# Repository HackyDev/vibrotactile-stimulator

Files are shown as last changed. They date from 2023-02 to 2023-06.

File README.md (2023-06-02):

# vibrotactile-stimulator

This DIY device is for vibrotactile stimulation and consists of 8 vibration modules and a NodeMCU controller. The frequency, vibration duration, and other settings can be adjusted using a web browser through WIFI. It can be built for less than $20  (access to a 3D printer required).

This device does not have a specific designated use, so it can be used for any purpose of your choice. The initial settings are set to zero, and you will need to adjust them through a graphical interface to your own values.

Please note that this device was built by a hobbyist for personal use only and has not been tested to meet any safety standards or requirements. The code running on the controller may also contain bugs.

The software is likely to be more valuable since it can work with a variety of similar devices. In contrast, the hardware was assembled using whatever materials were available and may require a significant amount of effort to put together, including soldering and gluing. Additionally, the parts used may not be ideal, and I provide some suggestions for improvement throughout the document.

The repository will be updated with more information in the future. If you find it helpful for your own projects, please consider starring the repository. You can contact me at hackydev@gmail.com

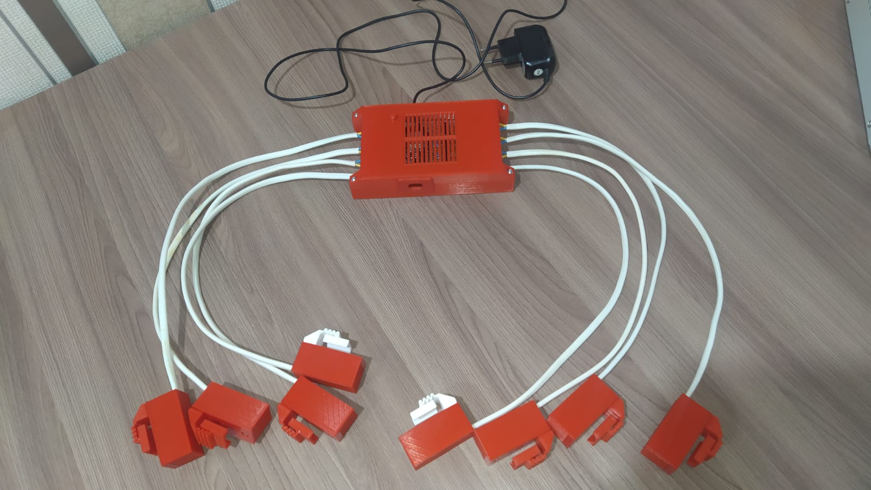
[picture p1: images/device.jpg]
vibrotactile stimulation device


## Settings

The device generates a WIFI network named "vtstim". The default password is 12345678. Upon connecting to this network, you can access the device's settings page by entering "192.168.1.1" in your browser's address bar. From there, you can make various adjustments and update the device in real-time.

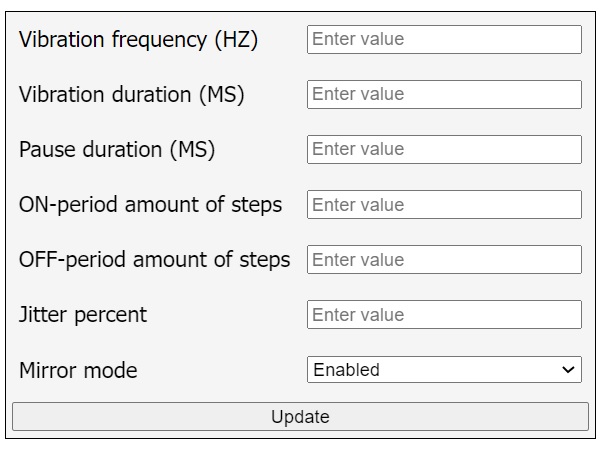
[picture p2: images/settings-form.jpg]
vibrotactile stimulation settings form


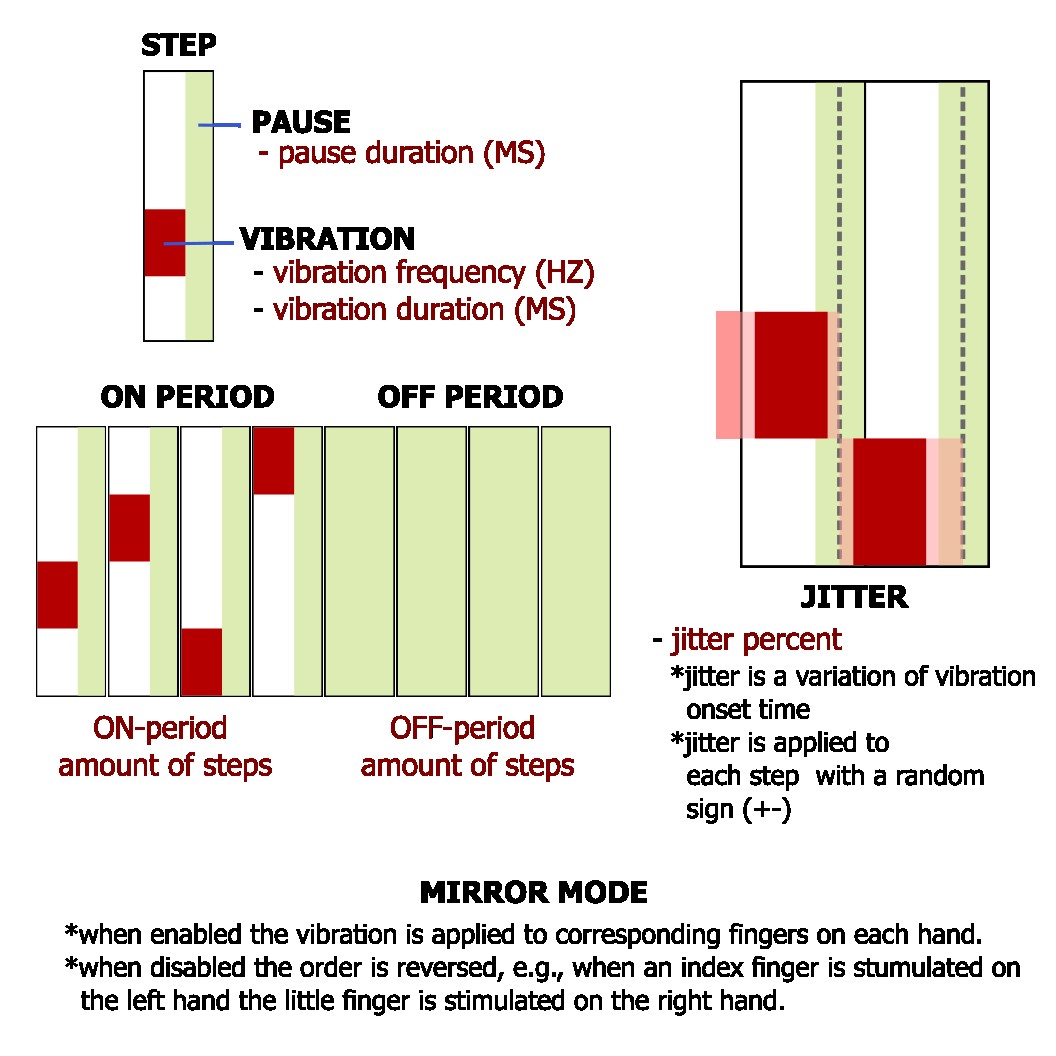
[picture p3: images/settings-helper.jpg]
vibrotactile stimulation settings helper


## Controller

The controller utilizes a [NodeMCU](https://www.amazon.com/OLatus-OL-nodeMCU-CH340-Wireless-Internet-development/dp/B07BM58B9K), which is compatible with Arduino and allows for the reuse of code in your Arduino projects with some modifications. The board in Arduino IDE is [NodeMCU 1.0 (ESP-12E Module)](https://docs.platformio.org/en/stable/boards/espressif8266/nodemcuv2.html).

The system is composed of a NodeMCU unit, 8 220 Ohm resistors, 8 DIY vibrotactile modules, 8 1N4007 diodes, and 8 IRF1406 MOSFET transistors, as shown in the schematics below.

I initially utilized BJT transistors, but they resulted in the NodeMCU being unable to boot up. This was due to these transistors grounding certain controller pins, which prevents the NodeMCU from starting up. To address this issue, MOSFET transistors are required.

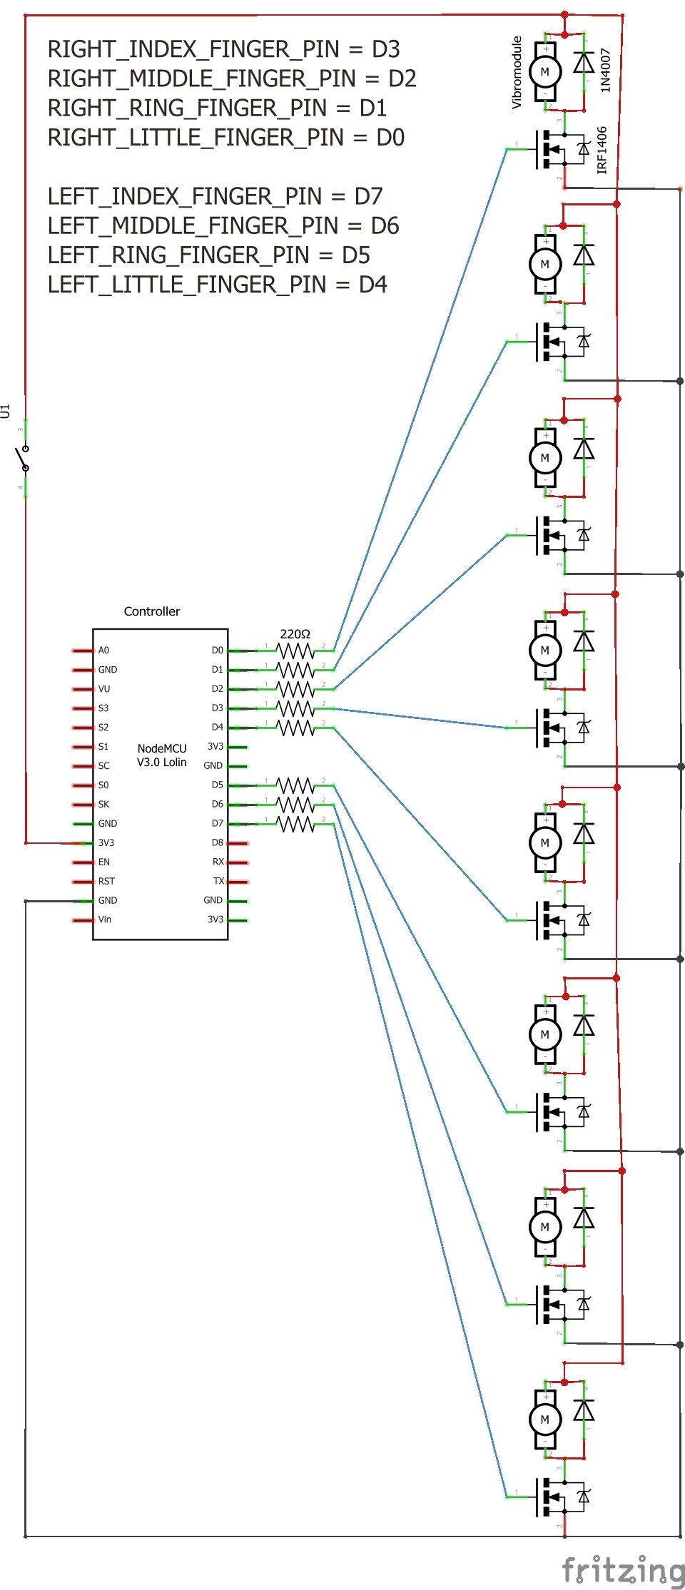
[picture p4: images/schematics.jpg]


I haven't included *.stl files for the controller cover because it's unlikely that they will fit your specific controller hardware. However, I have provided a Blender file, so you can make edits and customize it according to your requirements.

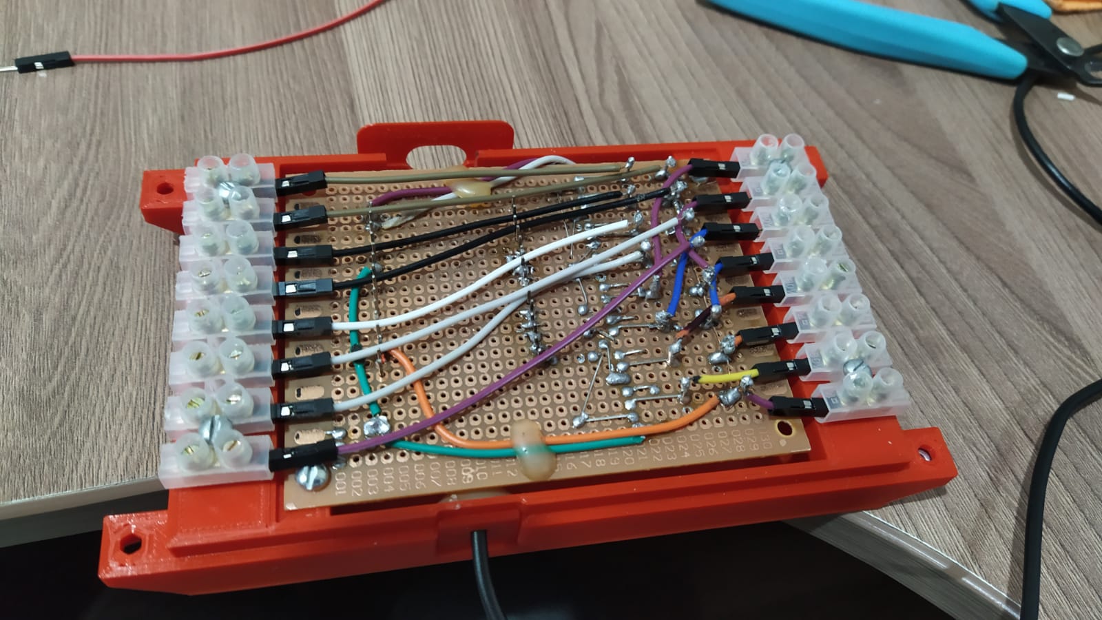
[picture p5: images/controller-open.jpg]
vibration stimulator controller open

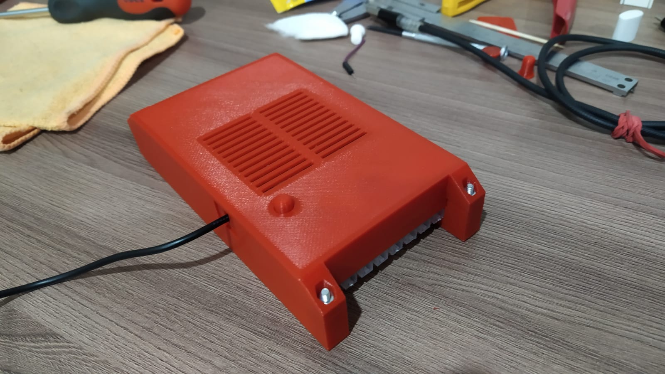
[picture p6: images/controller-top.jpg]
vibration stimulator controller top


## Vibration module

The vibration module consists of 3D printed parts, a small 10x10x1 permanent neodymium magnet, and a magnetic coil extracted from a power relay. Assembly can be quite time-consuming. For future versions, I would consider using an audio exciter such as [this one](https://www.tectonicaudiolabs.com/product/teax09c005-8/)

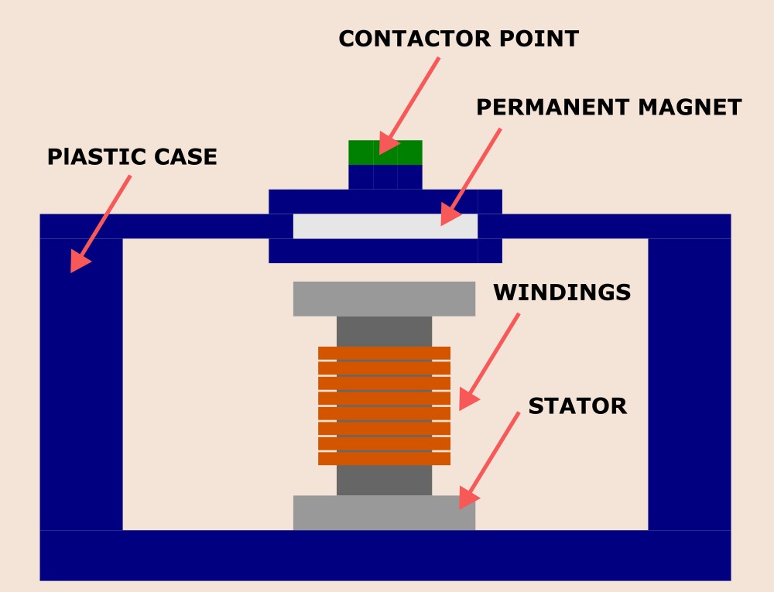
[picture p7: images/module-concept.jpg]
vibration module concept


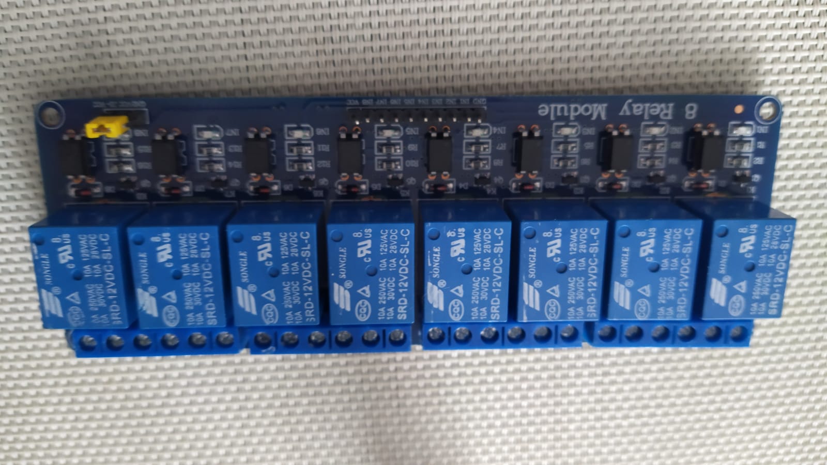
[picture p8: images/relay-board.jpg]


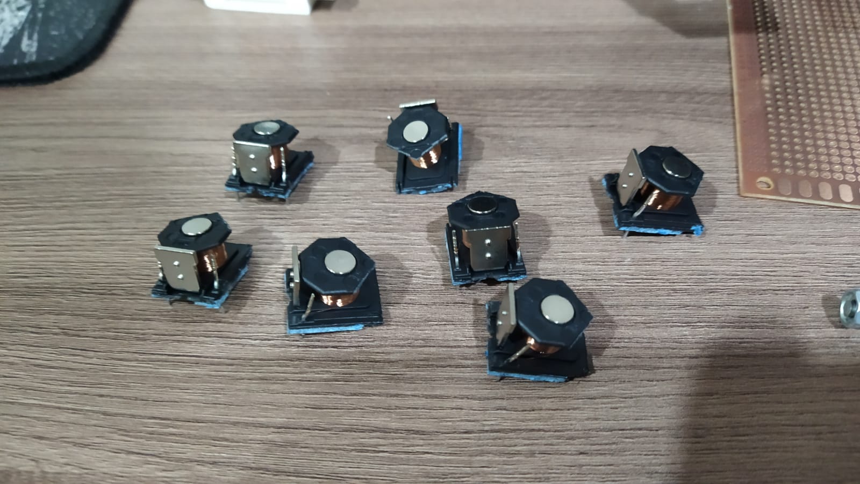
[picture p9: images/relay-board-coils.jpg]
Relay coils


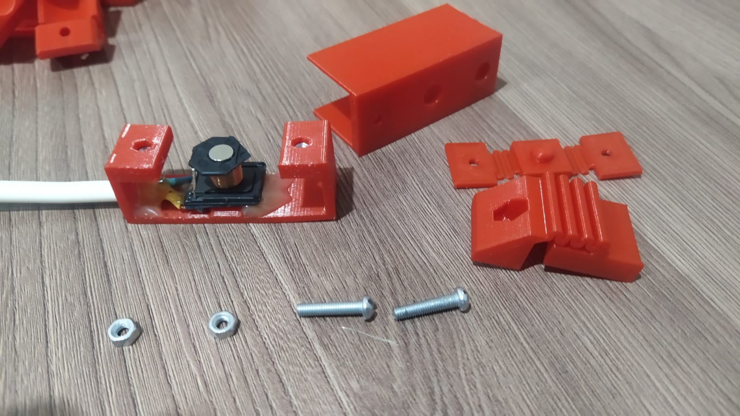
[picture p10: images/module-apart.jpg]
vibration module apart


When you print a spring, the printer will pause in the middle of the print to allow you to insert the magnet into the designated hole. Once you have done this, you can resume printing, and the magnet will be securely held inside the spring, eliminating the need for any gluing

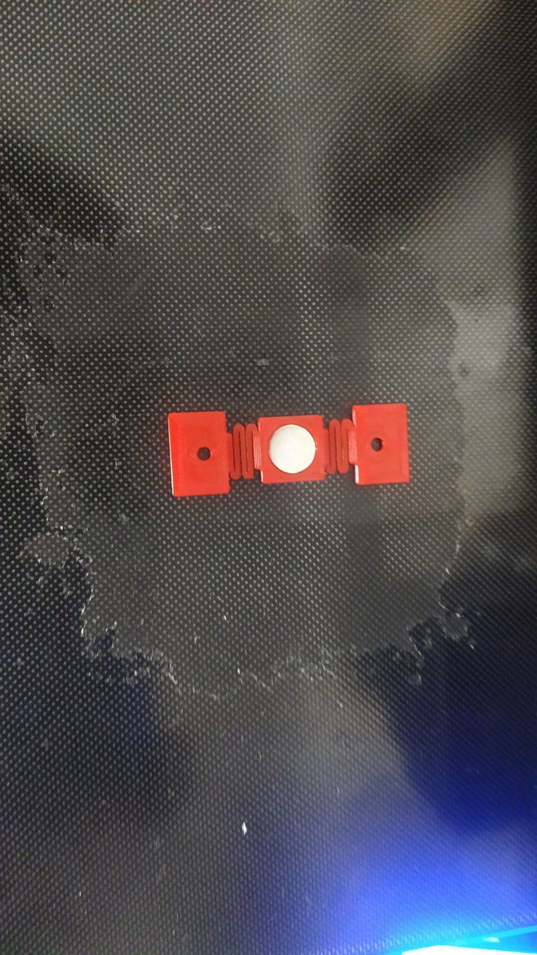
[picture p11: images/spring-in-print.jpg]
vibration module spring with magnet


The latch on top of the finger module is designed for relatively small fingers. You may need to adjust its height in the provided Blender file. Alternatively, you can place a shim below this part to achieve the desired fit

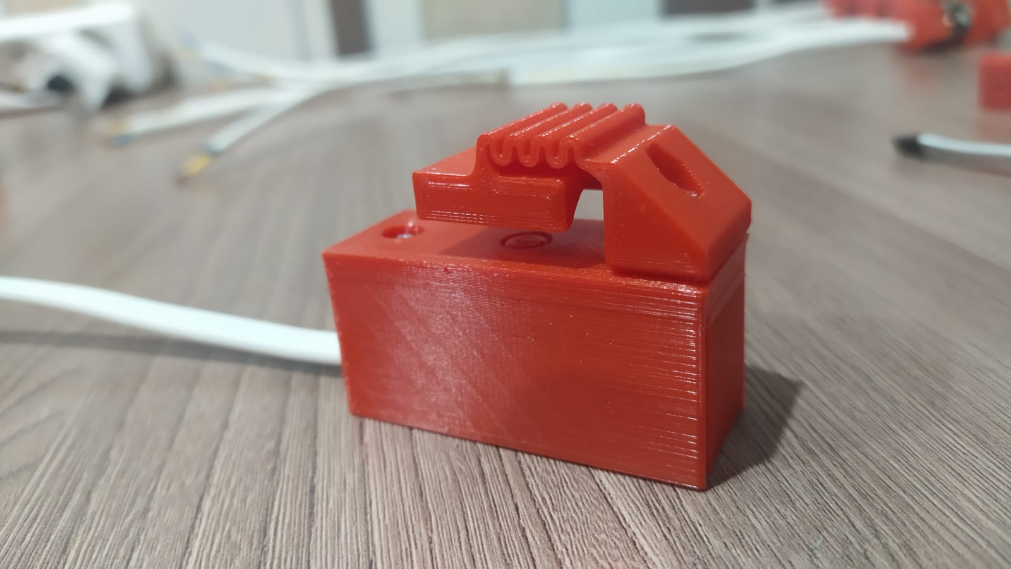
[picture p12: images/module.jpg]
vibration module


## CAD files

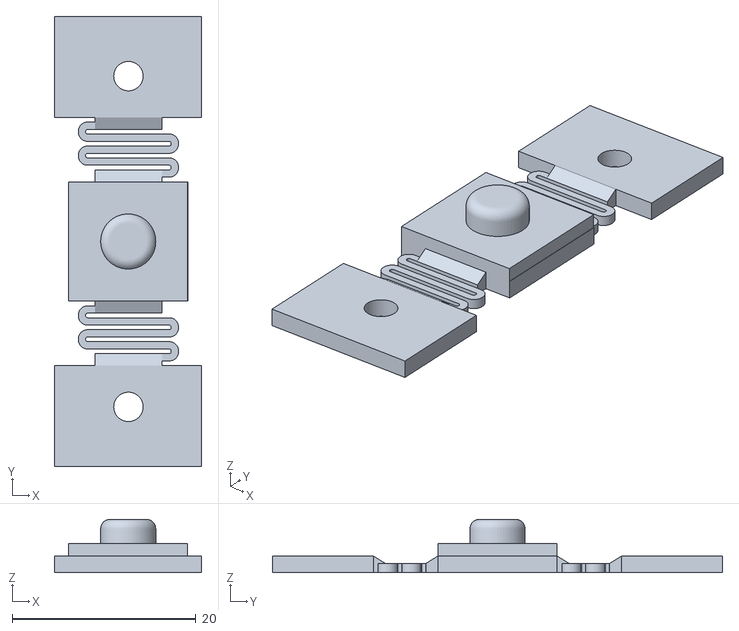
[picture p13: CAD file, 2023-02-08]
models/module/stl/1.0.0/vm-spring_2.4.0.stl
16.0 x 49.0 x 5.80

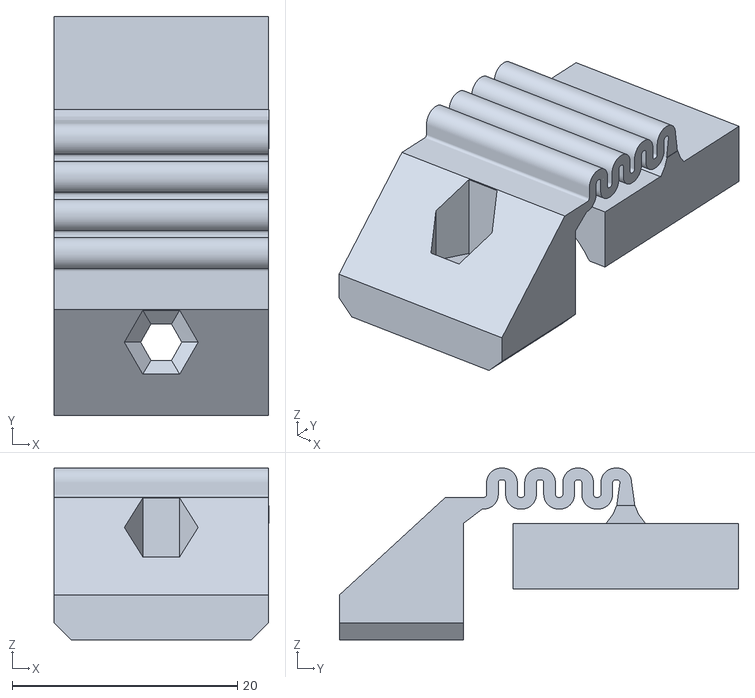
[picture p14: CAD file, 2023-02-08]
models/module/stl/1.0.0/vm-latch_2.4.0.stl
19.1 x 35.4 x 15.2

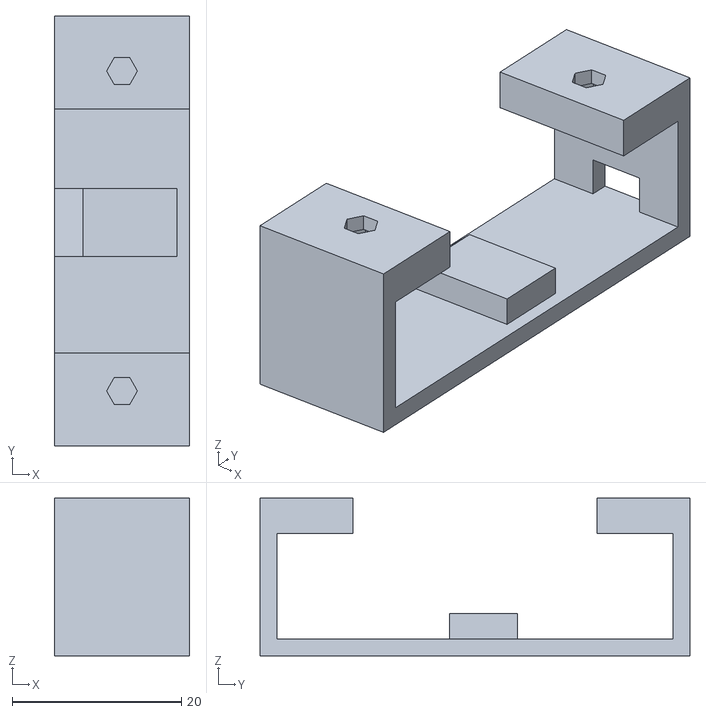
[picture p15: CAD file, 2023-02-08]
models/module/stl/1.0.0/vm-base_2.4.0.stl
16.0 x 50.8 x 18.7

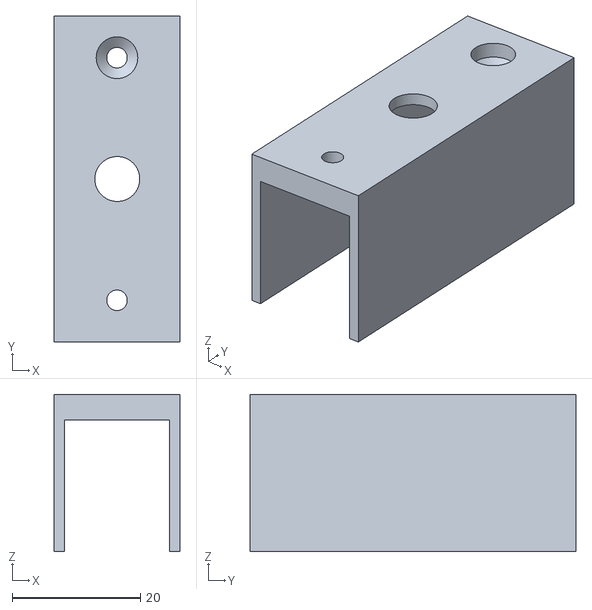
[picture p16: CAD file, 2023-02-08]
models/module/stl/1.0.0/vm-shell_2.4.0.stl
19.6 x 50.8 x 24.5

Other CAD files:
models/controller/controller.blend
models/module/module.blend

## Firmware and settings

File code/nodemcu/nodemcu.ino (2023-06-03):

// https://lastminuteengineers.com/creating-esp8266-web-server-arduino-ide/
#include <ESP8266WiFi.h>
#include <ESP8266WebServer.h>
#include <EEPROM.h>

const char* ssid = "vtstim";  // Enter SSID here
const char* password = "12345678";  // Enter Password here

enum FingerPin {
  RIGHT_INDEX_FINGER_PIN = D3,
  RIGHT_MIDDLE_FINGER_PIN = D2,
  RIGHT_RING_FINGER_PIN = D1,
  RIGHT_LITTLE_FINGER_PIN = D0,
  LEFT_INDEX_FINGER_PIN = D7,
  LEFT_MIDDLE_FINGER_PIN = D6,
  LEFT_RING_FINGER_PIN = D5,
  LEFT_LITTLE_FINGER_PIN = D4
};

enum State {
  NONE,
  STEP,
  VIBRATION,
  PULSE_ON,
  PULSE_OFF,
  PAUSE
};

struct UserSettings {
  int vibrationFrequencyHz;
  int vibrationDurationMs;
  int pauseDurationMs;
  int onPeriodAmountOfSteps;
  int offPeriodAmountOfSteps;
  int jitterPercent;
  bool mirrorModeEnabled;
};

class RandomProvider {
  private:
    int _sequencePosition = 0;
    long _sequenceStorage[3] = { 0, 0, 0 };
    long _previousRand = 0;
    long _currentRand = 0;

  public:
    long getRandomNumber() {
      _previousRand = _currentRand; 
      _currentRand = generateUniqueRandom();
      _sequenceStorage[_sequencePosition] = _currentRand;
      if (_sequencePosition++ > 2) {
        reset();
      }
      return _currentRand - 1;
    }
    void reset() {
      _sequenceStorage[0] = 0;
      _sequenceStorage[1] = 0;
      _sequenceStorage[2] = 0;
      _sequencePosition = 0;
    }
  private:
    long generateUniqueRandom() {
      long rand = random(1, 5);
      while (isDuplicate(rand)) {
        rand = random(1, 5);
      }
      return rand;
    }

    bool isDuplicate(long num) {
      return _sequenceStorage[0] == num || _sequenceStorage[1] == num || _sequenceStorage[2] == num || _previousRand == num;
    }
};

class Timer {
  private:
    unsigned long _startedAt;
    unsigned long _endsAt;
    unsigned long _duration;
    bool _hasOverflowed;
    bool _isMillis;
  unsigned long getTime () {
    if (_isMillis) {
      return millis();
    } else {
      return micros();
    }
  }
  public:
    Timer (bool isMillis) {
      _isMillis = isMillis;
    }
    const unsigned long& startedAt = _startedAt;
    void start(unsigned long durationMicroseconds) {
      _startedAt = getTime();
      _endsAt = _startedAt + durationMicroseconds;
      _duration = durationMicroseconds;
      _hasOverflowed = _endsAt < _startedAt;
    }
    bool isStarted () {
      return _duration > 0;
    }
    unsigned long getRunTime () {
      if (isStarted()) {
        return getTime() - _startedAt;
      } else {
        return 0;
      }
    }
    unsigned long isDone () {
      if (_duration == 0) {
        return false;
      }
      unsigned long now = getTime();
      if (_hasOverflowed) {
        return now + _duration > _startedAt;
      } else {
        return now > _endsAt;
      }
    }
    void reset () {
      _startedAt = 0;
      _endsAt = 0;
      _duration = 0;
      _hasOverflowed = false;
    }
};

class UserSettingsStorage {
  private:
    UserSettings _defaultUserSettings;
  public:
    int checkValue = 11111;
    int checkAddress = 100;
    int dataAddress = 200;

    UserSettingsStorage (UserSettings defaultUserSettings) {
      _defaultUserSettings = defaultUserSettings;
    }
    bool put(UserSettings userSettings) {
      EEPROM.put(dataAddress, userSettings);
      EEPROM.put(checkAddress, checkValue);
      return EEPROM.commit();
    }
    UserSettings get () {
      UserSettings userSettings;
      int checkValueStored;
      EEPROM.get(checkAddress, checkValueStored);
      if (checkValue == checkValueStored) {
        EEPROM.get(dataAddress, userSettings);
        return userSettings;
      } else {
        return getDefaultSettings();
      }
    }
    UserSettings getDefaultSettings () {
      return _defaultUserSettings;
    }
    void printUserSettings (UserSettings userSettings) {
      Serial.println("");
      Serial.print("vibrationFrequencyHz:");
      Serial.println(userSettings.vibrationFrequencyHz);
      Serial.print("vibrationDurationMs:");
      Serial.println(userSettings.vibrationDurationMs);
      Serial.print("mirrorModeEnabled:");
      Serial.println(userSettings.mirrorModeEnabled);
      Serial.print("onPeriodAmountOfSteps:");
      Serial.println(userSettings.onPeriodAmountOfSteps);
      Serial.print("offPeriodAmountOfSteps:");
      Serial.println(userSettings.offPeriodAmountOfSteps);
      Serial.print("jitterPercent:");
      Serial.println(userSettings.jitterPercent);
      Serial.print("mirrorModeEnabled:");
      Serial.println(userSettings.mirrorModeEnabled);
    }
};

class App {
  private:
    State _state = State::NONE;
    // TODO ADD TYPE CHECK to UserSettingsStorage
    UserSettingsStorage _userSettingsStorage = UserSettingsStorage({ 0, 0, 0, 0, 0, 0, false });
    UserSettings _userSettings = _userSettingsStorage.getDefaultSettings();
    unsigned long _pulseOnDurationUs = 0;
    unsigned long _pulseOffDurationUs = 0;
    int _leftHandActivePin = 0;
    int _rightHandActivePin = 0;
    int _step = 0;
    bool _isOnPeriod = true;
    long _jitterValueMu = 0;
    long _currentJitterValueMu = 0;
    Timer _muTimer = Timer(false);
    Timer _muTimer2 = Timer(false);
    RandomProvider _randomProvider = RandomProvider();
    constexpr static int _fingerPins[2][4] = {
      { 
        LEFT_INDEX_FINGER_PIN,
        LEFT_MIDDLE_FINGER_PIN,
        LEFT_RING_FINGER_PIN,
        LEFT_LITTLE_FINGER_PIN
      },
      {
        RIGHT_INDEX_FINGER_PIN,
        RIGHT_MIDDLE_FINGER_PIN,
        RIGHT_RING_FINGER_PIN,
        RIGHT_LITTLE_FINGER_PIN
      }
    };
    constexpr static int _fingerPinsReversed[2][4] = {
      { 
        LEFT_LITTLE_FINGER_PIN,
        LEFT_RING_FINGER_PIN,
        LEFT_MIDDLE_FINGER_PIN,
        LEFT_INDEX_FINGER_PIN
      },
      {
        RIGHT_LITTLE_FINGER_PIN,
        RIGHT_RING_FINGER_PIN,
        RIGHT_MIDDLE_FINGER_PIN,
        RIGHT_INDEX_FINGER_PIN
      }
    };
    String _stateStr[6] = {
        "NONE",
        "STEP",
        "VIBRATION",
        "PULSE_ON",
        "PULSE_OFF",
        "PAUSE"
    };
    void applyUserSettings (UserSettings userSettings) {
      if (userSettings.vibrationFrequencyHz > 0) {
        _pulseOnDurationUs = 1000000 / (userSettings.vibrationFrequencyHz * 2);
        _pulseOffDurationUs = 1000000 / (userSettings.vibrationFrequencyHz * 2);
      } else {
        _pulseOnDurationUs = 0;
        _pulseOffDurationUs = 0;
      }
    }
    unsigned long getPauseDuration () {
      return (_userSettings.pauseDurationMs * 1000) + _currentJitterValueMu;
    }
    unsigned long getVibrationDuration () {
      return _userSettings.vibrationDurationMs * 1000;
    }
    void setJitterValue () {
      _jitterValueMu = ((_userSettings.pauseDurationMs * 1000) / 2) * (_userSettings.jitterPercent / 100);
    }
    void updateCurrentJitterValue () {
      if (_step % 2 > 0) {
        long rand = random(0, 2);
        if (rand > 0) {
          _currentJitterValueMu = _jitterValueMu;
        } else {
          _currentJitterValueMu = -_jitterValueMu;
        }
      } else {
        if (_currentJitterValueMu > 0) {
          _currentJitterValueMu = -_jitterValueMu;
        } else {
          _currentJitterValueMu = _jitterValueMu;
        }
      }
    }
    bool updateState () {
      State state = _state;
      switch (_state) {
        case State::NONE:
          _state = State::STEP;
          break;
        case State::STEP:
          _state = State::VIBRATION;
          _muTimer2.start(getVibrationDuration());
          break;
        case State::VIBRATION:
          _state = State::PULSE_ON;
          _muTimer.start(_pulseOnDurationUs);
          break;
        case State::PULSE_ON:
          if (_muTimer2.isDone()) {
            _state = State::PAUSE;
            _muTimer2.reset();
            _muTimer.reset();
          } else if (_muTimer.isDone()) {
            _state = State::PULSE_OFF;
            _muTimer.reset();
            _muTimer.start(_pulseOffDurationUs);
          }
          break;
        case State::PULSE_OFF:
          if (_muTimer2.isDone()) {
            _state = State::PAUSE;
            _muTimer2.reset();
            _muTimer.reset();
          } else if (_muTimer.isDone()) {
            _state = State::PULSE_ON;
            _muTimer.reset();
            _muTimer.start(_pulseOnDurationUs);
          }
          break;
        case State::PAUSE:
          if (_muTimer2.isStarted()) {
            if (_muTimer2.isDone()) {
              _state = State::STEP;
              _muTimer2.reset();
            }
          } else {
            _muTimer2.start(getPauseDuration());
          }
          break;
      }
      return state != _state;
  }
  void updateActivePins () {
    int num = _randomProvider.getRandomNumber();
    _leftHandActivePin = _fingerPins[0][num];
    if (_userSettings.mirrorModeEnabled) {
      _rightHandActivePin = _fingerPins[1][num];
    } else {
      _rightHandActivePin = _fingerPinsReversed[1][num];
    }
  }
  void newStepHandler () {
    if (_isOnPeriod) {
      if (_step >= _userSettings.onPeriodAmountOfSteps) {
        _isOnPeriod = false;
        _step = 0;
      }
    } else {
      if (_step >= _userSettings.offPeriodAmountOfSteps) {
        _isOnPeriod = true;
        _step = 0;
        _randomProvider.reset();
      }
    }
    updateActivePins();
    updateCurrentJitterValue();
    _step++;
  }
  void initPins () {
    for (int i = 0; i < 4; i++) {
      pinMode(_fingerPins[0][i], OUTPUT);
      pinMode(_fingerPins[1][i], OUTPUT);
    }
  }
  void printState (State state) {
    Serial.print("STATE: ");
    Serial.println(_stateStr[state]);
  }
  public:
    void setup () {
      randomSeed(analogRead(A0));
      EEPROM.begin(512);
      _userSettings = _userSettingsStorage.get();
      _userSettingsStorage.printUserSettings(_userSettings);
      applyUserSettings(_userSettings);
      setJitterValue();
      initPins();
    }
    void update () {
      bool isStateChanged = updateState();
      if (isStateChanged) {
        switch (_state) {
          case State::STEP:
            newStepHandler();
            break;
          case State::PAUSE:
            digitalWrite(_leftHandActivePin, LOW);
            digitalWrite(_rightHandActivePin, LOW);
            break;
          case State::PULSE_ON:
            if (_isOnPeriod) {
              digitalWrite(_leftHandActivePin, HIGH);
              digitalWrite(_rightHandActivePin, HIGH);
            }
            break;
          case State::PULSE_OFF:
            digitalWrite(_leftHandActivePin, LOW);
            digitalWrite(_rightHandActivePin, LOW);
            break;
        }
      }
    }
    bool setUserSettings (UserSettings userSettings) {
      bool success = _userSettingsStorage.put(userSettings);
      if (success) {
        _userSettings = userSettings;
        applyUserSettings(_userSettings);
      }
      return success;
    }
    UserSettings getUserSettings () {
      return _userSettings;
    }
    
  bool setUserSettingsFromHttpRequest (ESP8266WebServer &server) {
    UserSettings userSettings = getUserSettings();
    for (int i = 0; i < server.args(); i++) {
      String argValue = server.arg(i);
      String argName = server.argName(i);
      if (argName == "vibrationFrequencyHz") {
        userSettings.vibrationFrequencyHz = argValue.toInt();
      } else if (argName == "vibrationDurationMs") {
        userSettings.vibrationDurationMs = argValue.toInt();
      } else if (argName == "pauseDurationMs") {
        userSettings.pauseDurationMs = argValue.toInt();
      } else if (argName == "onPeriodAmountOfSteps") {
        userSettings.onPeriodAmountOfSteps = argValue.toInt();
      } else if (argName == "offPeriodAmountOfSteps") {
        userSettings.offPeriodAmountOfSteps = argValue.toInt();
      } else if (argName == "jitterPercent") {
        userSettings.jitterPercent = argValue.toInt();
      } else if (argName == "mirrorModeEnabled") {
        userSettings.mirrorModeEnabled = argValue == "true";
      }
    }
    return setUserSettings(userSettings);
  }
};

App app = App();

// SERVER
IPAddress local_ip(192,168,1,1);
IPAddress gateway(192,168,1,1);
IPAddress subnet(255,255,255,0);
ESP8266WebServer server(80);

void setup() {
  Serial.begin(115200);
  while (!Serial) {
    ; // wait for serial port to connect. Needed for native USB port only
  }
  // SERVER
  WiFi.softAP(ssid, password);
  WiFi.softAPConfig(local_ip, gateway, subnet);
  delay(100);
  server.on("/", serveIndex);
  server.on("/update", serveUpdate);
  server.onNotFound(serveIndex);
  server.begin();

  // APP
  app.setup(); // return mode and disable/prevent init wifi and server if needed (for performance)
}

void loop() {
  server.handleClient();
  app.update();
}

// SERVER

void serveIndex() {
  server.send(200, "text/html", getUpdateUserSettingsFormHtml(app.getUserSettings()));
}
void serveUpdate() {
  bool success = app.setUserSettingsFromHttpRequest(server);
  if (success) {
    server.send(200, "text/html", getUpdateUserSettingsSuccessHtml()); 
  } else {
    server.send(200, "text/html", getUpdateUserSettingsFailHtml());
  }
}

// https://flems.io/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

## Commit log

2023-02-22 fixed divide by 0 issue
    [nodemcu.ino]
2023-06-01 added finger mappings to the pins on the schematics.jpg
2023-06-01 added schematics.svg
2023-06-02 added nodemcu board info
2023-06-02 fixed random generation issues
    [nodemcu.ino]
